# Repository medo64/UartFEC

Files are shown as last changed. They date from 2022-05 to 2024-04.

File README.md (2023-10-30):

[UART Framework Expansion Card](https://medo64.com/uartframecard/)
==================================================================

This Framework laptop expansion card will show up on your system as a serial
device and allow for a non-isolated serial UART communication up to 3 Mbaud
baud rate.

Please note that this card is not using RS-232 but TTL (either 3.3V or 5V)
voltage levels (depending on solder-jumper position).

## UART Pinout

To connect to this board, one has to use a 3-pin JST XH connector. The following
table represents the pinout, pin 1 being on the left as looking into the
expansion card.

| # | Ref | Description |
|--:|:---:|---|
| 1 | RXD | Receive (TTL: 5V or 3.3V) |
| 2 | GND | Ground connection |
| 3 | TXD | Transmit (TTL: 5V or 3.3V) |

As power consumption is way below 10 mA, wires can be almost any AWG. I would
recommend using 24 AWG wire 0.25 mm² as they allow for greater compatibility
with other connectors.

## Supported Speeds

This board employs the FT232R as its UART chip, and consequently, it supports
all the baud rates this chip [can handle](https://ftdichip.com/Documents/AppNotes/AN232B-05_BaudRates.pdf).
The table below lists the standard baud rates.

| Baud rate | Actual | Error | Divisor |
|---:|---:|---:|---:|
| 300 | 300 | 0.00% |  10000.000 |
| 600 | 600 | 0.00% | 5000.000 |
| 1,200 | 1,200 | 0.00% | 2500.000 |
| 1,800 | 1,800 | 0.00% | 1666.625 |
| 2,400 | 2,400 | 0.00% | 1250.000 |
| 4,800 | 4,800 | 0.00% | 625.000 |
| 7,200 | 7,201 | 0.01% | 416.625 |
| 9,600 | 9,600 | 0.00% | 312.500 |
| 14,400 | 14,406 | 0.04% | 208.250 |
| 19,200 | 19,200 | 0.00% | 156.250 |
| 28,800 | 28,812 | 0.04% | 104.125 |
| 38,400 | 38,400 | 0.00% | 78.125 |
| 57,600 | 57,692 | 0.16% | 52.000 |
| 115,200 | 115,385 | 0.16% | 26.000 |
| 230,400 | 230,769 | 0.16% | 13.000 |
| 460,800 | 461,538 | 0.16% | 6.500 |
| 921,600 | 923,077 | 0.16% | 3.250 |
| 1,000,000 | 1,000,000 | 0.00% | 3.000 |

While chip does support baud rates up to 3 Mbaud, granularity of such rates
is severely limited.

---
*You can check my blog and other projects at [www.medo64.com](https://www.medo64.com/electronics/).*

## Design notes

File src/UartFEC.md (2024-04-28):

### UartIsoFEC Parts

|  # | Part | RefDes  | Preferred Part Number |
|---:|---|---|---|
|  1 | C 10nF X7R 16V (0805) | C1 | 399-17617-1-ND |
|  3 | C 100nF X7R 16V (0805) | C2-C4 | 478-5311-1-ND |
|  1 | C 4.7uF X5R 16V (0805) | C5 | 1276-1244-1-ND |
|  1 | D TVS 5V SM05T1G (SOT23-3) | D1 | SM05T1GOSCT-ND |
|  2 | DS LED (0805) | DS1-DS2 | 475-1415-1-ND |
|  1 | J USB C, plug, straddle 0.8mm | J1 | WM12855-ND |
|  1 | J JST XH Vertical (3w) | J2 | 455-2248-ND |
|  1 | L Ferrite 600R@100Mhz | L1 | 240-2390-1-ND |
|  1 | Q P-MOSFET DMP3099L-13 (SOT23) | Q1 | DMP3099L-13DICT-ND |
|  3 | R 1K 0.125W (0805) | R1-R3 | RMCF0805FT1K00CT-ND |
|  1 | R 5.1K 0.125W (0805) | R4 | RMCF0805FT5K10CT-ND |
|  1 | R 10K 0.125W (0805) | R5 | RMCF0805FT10K0CT-ND |
|  1 | U Transciever Uart FT232R (SSOP-28) | U1 | 768-FT232RNL-TUBE-ND |
|  2 | H Screw M2x3mm | - | - |

#### Board Size

| | Dimensions | Area | Thickness |
|---|---|---|---|
| PCB |  24.0 x 27.9 mm | 1.1 in² | 0.8 mm |

#### FTDI Configuration

| Setting | Value  |
|---|---|
| CBUS0 | TXLED# |
| CBUS1 | RXLED# |
| CBUS2 | TXDEN  |
| CBUS3 | PWREN# |
| CBUS4 | SLEEP# |

#### Power

| Property | Value  |
|---|---:|
| Voltage  | 5 V |
| Current  | 100 mA |

#### Jumpers

##### 3V3

This jumper has to be bridged for operation in 3.3V. If this jumper is bridged,
5V jumper MUST NOT be bridged too.

##### 5V

This jumper has to be bridged for operation in 5V. If this jumper is bridged,
3.3V jumper MUST NOT be bridged too.

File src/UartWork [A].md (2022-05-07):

### UartWork Parts

|  # | Part | RefDes  | Preferred Part Number |
|---:|---|---|---|
|  1 | C 100nF X7R 16V (0805) | C1 | 478-5311-1-ND |
|  1 | C 470nF X7R 16V (0805) | C2 | 1276-1199-1-ND |
|  2 | C 1uF X7R 16V (0805) | C3-C4 | 1276-6471-1-ND |
|  2 | DS LED (0805) | DS1-DS2 | 475-1415-1-ND |
|  1 | F 200 mA fast (0805) | F1 | 507-1811-1-ND |
|  1 | J JST XH Vertical (3w) | J1 | 455-2248-ND |
|  1 | P USB C, plug, straddle 0.8mm | P1 | WM12855-ND |
|  2 | R 1K 0.125W (0805) | R1-R2 | RMCF0805FT1K00CT-ND |
|  1 | R 5.1K 0.125W (0805) | R3 | RMCF0805FT5K10CT-ND |
|  1 | U MCP2221 (SOIC-14) | U1 | MCP2221-I/SL-ND |
|  1 | VR AP2138N-3.3TRG1 (SOT23-3) | VR1 | AP2138N-3.3TRG1DICT-ND |

#### Board Size

| | Dimensions | Area | Thickness |
|---|---|---|---|
| PCB |  24.0 x 27.9 mm | 1.1 in² | 0.8 mm |

#### Power

| Property | Value  |
|---|---:|
| Voltage  | 5 V |
| Current  | 100 mA |

#### Jumpers

##### 3V3

This jumper has to be bridged for operation in 3.3V. If this jumper is bridged,
5V jumper MUST NOT be bridged too.

##### 5V

This jumper has to be bridged for operation in 5V. If this jumper is bridged,
3.3V jumper MUST NOT be bridged too.

For operation at 5V, the following components can be omitted:
* C3-C4
* VR1

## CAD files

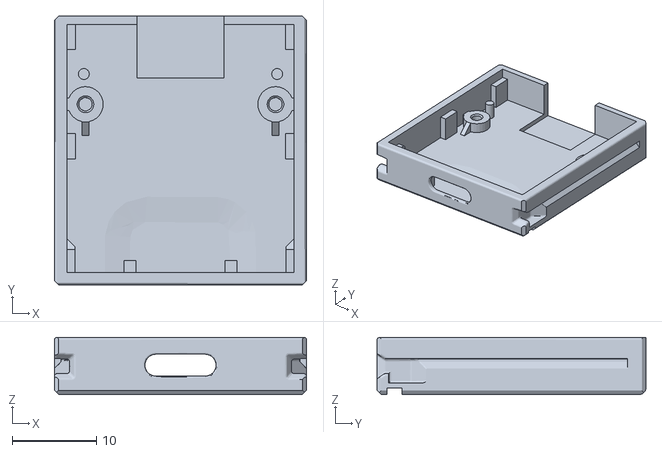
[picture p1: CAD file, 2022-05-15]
src/UartFEC Case Base.stl
30.0 x 32.0 x 6.80

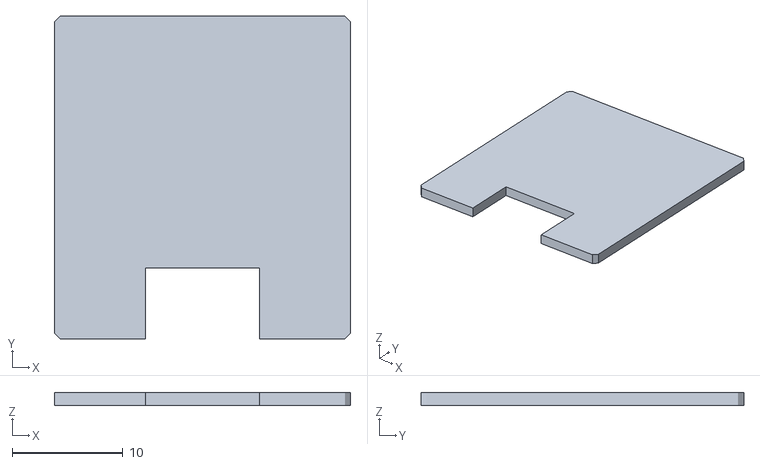
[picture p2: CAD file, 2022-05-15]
src/UartFEC Case Top.stl
26.7 x 29.1 x 1.20

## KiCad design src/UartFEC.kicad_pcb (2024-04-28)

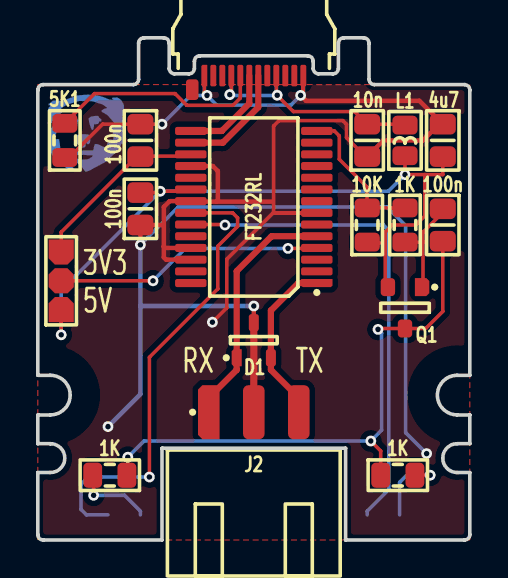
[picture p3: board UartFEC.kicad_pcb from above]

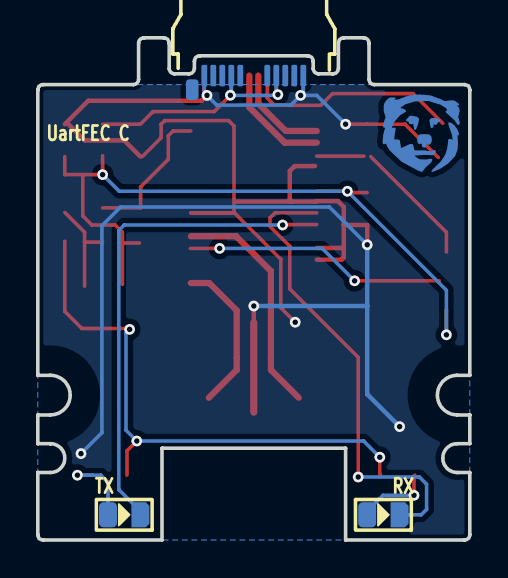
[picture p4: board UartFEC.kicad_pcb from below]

Board: 2 copper layers, 24.0 x 27.9 mm, 20 parts (3 on the bottom side), 17 nets.

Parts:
C1: 10n; C (0805)
C2, C3, C4: 100n; C (0805)
C5: 4u7; C (0805)
D1: SM05T1G; D TVS SM05T1G (SOT23-3)
DS1: RX; DS (0805)
DS2: TX; DS (0805)
ICON: Medo64; ICON Medo64
J1: 105444-0001; P USB C 3.2 Edge (24w)
J2: B3B-XH-A; J JST XH Edge [UART] (3w)
JP1: Jumper; JP Dual (1205)
L1: 600R; L (0805)
Q1: DMP3099L-13; Q MOSFET-P (SOT23-3)
R1, R2, R3: 1K; R (0805)
R4: 5K1; R (0805)
R5: 10K; R (0805)
U1: FT232RL; U Transciever UART FT232RL (SSOP-28)

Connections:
3V3: C3.2, JP1.3, U1.17
5V: C2.2, C5.2, JP1.1, L1.1, Q1.2, R5.1, U1.20
5V_SW: C4.2, Q1.3, R1.1, R2.1
A_CC: J1.A5, R4.2
GND: C1.1, C2.1, C3.1, C5.1, D1.3, J1.A1, J1.A12, J1.B01, J1.B12, J2.2, R4.1, U1.7, U1.18, U1.21, U1.25, U1.26
LED_RXD: DS1.1, U1.22
LED_RXD': DS1.2, R1.2
LED_TXD: DS2.1, U1.23
LED_TXD': DS2.2, R2.2
PWREN#: R3.1, R5.2, U1.14
PWREN#': C4.1, Q1.1, R3.2
RXD: D1.1, J2.1, U1.5
TXD: D1.2, J2.3, U1.1
USB_DM: J1.A7, U1.16
USB_DP: J1.A6, U1.15
USB_Vin: C1.2, J1.A4, J1.A9, J1.B04, J1.B09, L1.2
Vio: JP1.2, U1.4

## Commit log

2022-04-10 Added case
    [UartWork [A] CaseBase.stl, UartWork [A] CaseTop.stl]
2022-04-18 Moving LEDs to corner
2022-04-20 Updated pinout to RXD GND TXD
2022-04-21 Refactoring power a bit
2022-05-07 Longer pads on type-C connector
2022-05-07 Removed extra CC2 resistor
2022-05-09 Turned LEDs around
2022-05-09 Updated case STLs
    [UartWork [A] CaseBase.stl, UartWork [A] CaseTop.stl]
2022-06-21 Updated project name
    [UartFrameCard [A] CaseBase.stl, UartFrameCard [A] CaseTop.stl]
2022-06-26 New release with covert I2C support
    [UartFrameCard [B] Uart CaseBase.stl, UartFrameCard [B] Uart CaseTop.stl, UartFrameCard [B] Uart+I2C CaseBase.stl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]
2022-06-26 Added missing fuse connection
2022-06-26 Changes sensor I2C address to 0x4F (was 0x48)
2022-06-26 Added schematics
2022-06-26 Updated voltage output text
2022-06-26 Added output protection diode.
2022-06-26 Updated fuse model
2022-06-27 Changed shottky diode
2022-07-09 Adjusted shape for production reasons (slot width)
2023-09-18 Redesigned to use FT232R and removed I2C interface
    [UartFEC Case Base.stl, UartFEC Case Top.stl, UartFEC.kicad_pcb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]
2023-09-18 Added TVS protection
    [UartFEC.kicad_pcb]
2023-10-10 Larger silkscreen markings
    [UartFEC.kicad_pcb]
2023-10-25 Fixed reset pin (was GND before; now flloating)
    [UartFEC.kicad_pcb]
2023-10-25 Updated jumper and JST edge connector footprint
    [UartFEC.kicad_pcb]
2023-10-25 Swapping L1 and 10nF location
    [UartFEC.kicad_pcb]
2023-11-04 Added RTS/CTS loopback
    [UartFEC.kicad_pcb]
2023-11-13 Minor resistor move
    [UartFEC.kicad_pcb]
2023-11-13 Moved LEDs to bottom
    [UartFEC.kicad_pcb]
2023-12-26 Refactored LED control for standby
    [UartFEC.kicad_pcb]
2023-12-26 Removed internal RTS/CTS connection
    [UartFEC.kicad_pcb]
2023-12-30 Refactoring copper pour
    [UartFEC.kicad_pcb]
2024-01-28 Added MOSFET
2024-01-28 Moved LEDs a bit
    [UartFEC.kicad_pcb]
2024-01-31 Moved LEDs
    [UartFEC.kicad_pcb]
2024-04-02 Updated connector designators
    [UartFEC.kicad_pcb]
2024-04-28 Fixed refdes
    [UartFEC.kicad_pcb]
